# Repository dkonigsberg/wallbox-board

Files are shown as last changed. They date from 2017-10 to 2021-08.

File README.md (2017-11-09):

# Wallbox Interface Board

Seeburg Wall-O-Matic 100

## Introduction
This repository provides the [KiCad](http://kicad-pcb.org/) project
containing the complete circuit schematic, bill-of-materials, and
PCB layout for the Wall-O-Matic Interface Board.

The interface board is a device designed to take a Seeburg Wall-O-Matic
jukebox remote, a common sight on a sterotypical 1950's diner tabletop,
and interface it to a Sonos system via Wi-Fi using an ESP8266 (ESP-12S).

Wall-O-Matic Interface Board

The main repository for the schematics is:
https://github.com/dkonigsberg/wallbox-board

The source code for the firmware that runs on this board is here:
https://github.com/dkonigsberg/wallbox-code

A good overview of the project can be found in these blog posts:
* Part 1 - [Introduction](http://hecgeek.blogspot.com/2017/10/wall-o-matic-interface-1.html)
* Part 2 - [Procuring a Functional Wallbox](http://hecgeek.blogspot.com/2017/10/wall-o-matic-interface-2.html)
* Part 3 - [Decoding the Pulses](http://hecgeek.blogspot.com/2017/10/wall-o-matic-interface-3.html)
* Part 4 - [Inserting Coins](http://hecgeek.blogspot.com/2017/10/wall-o-matic-interface-4.html)
* Part 5 - [Designing the Circuit](http://hecgeek.blogspot.com/2017/10/wall-o-matic-interface-5.html)
* Part 6 - [Developing the Software](http://hecgeek.blogspot.com/2017/10/wall-o-matic-interface-6.html)

You can see a video about the project here:
* [Wallbox Interface Assembly and Testing](https://www.youtube.com/watch?v=2aR7-YdtxFc)

## Notes
The component libraries used in this project are a bit of a hack job, pulling
from many different sources. The KiCad cache file is included so that the
project can actually be opened without having to duplicate this.

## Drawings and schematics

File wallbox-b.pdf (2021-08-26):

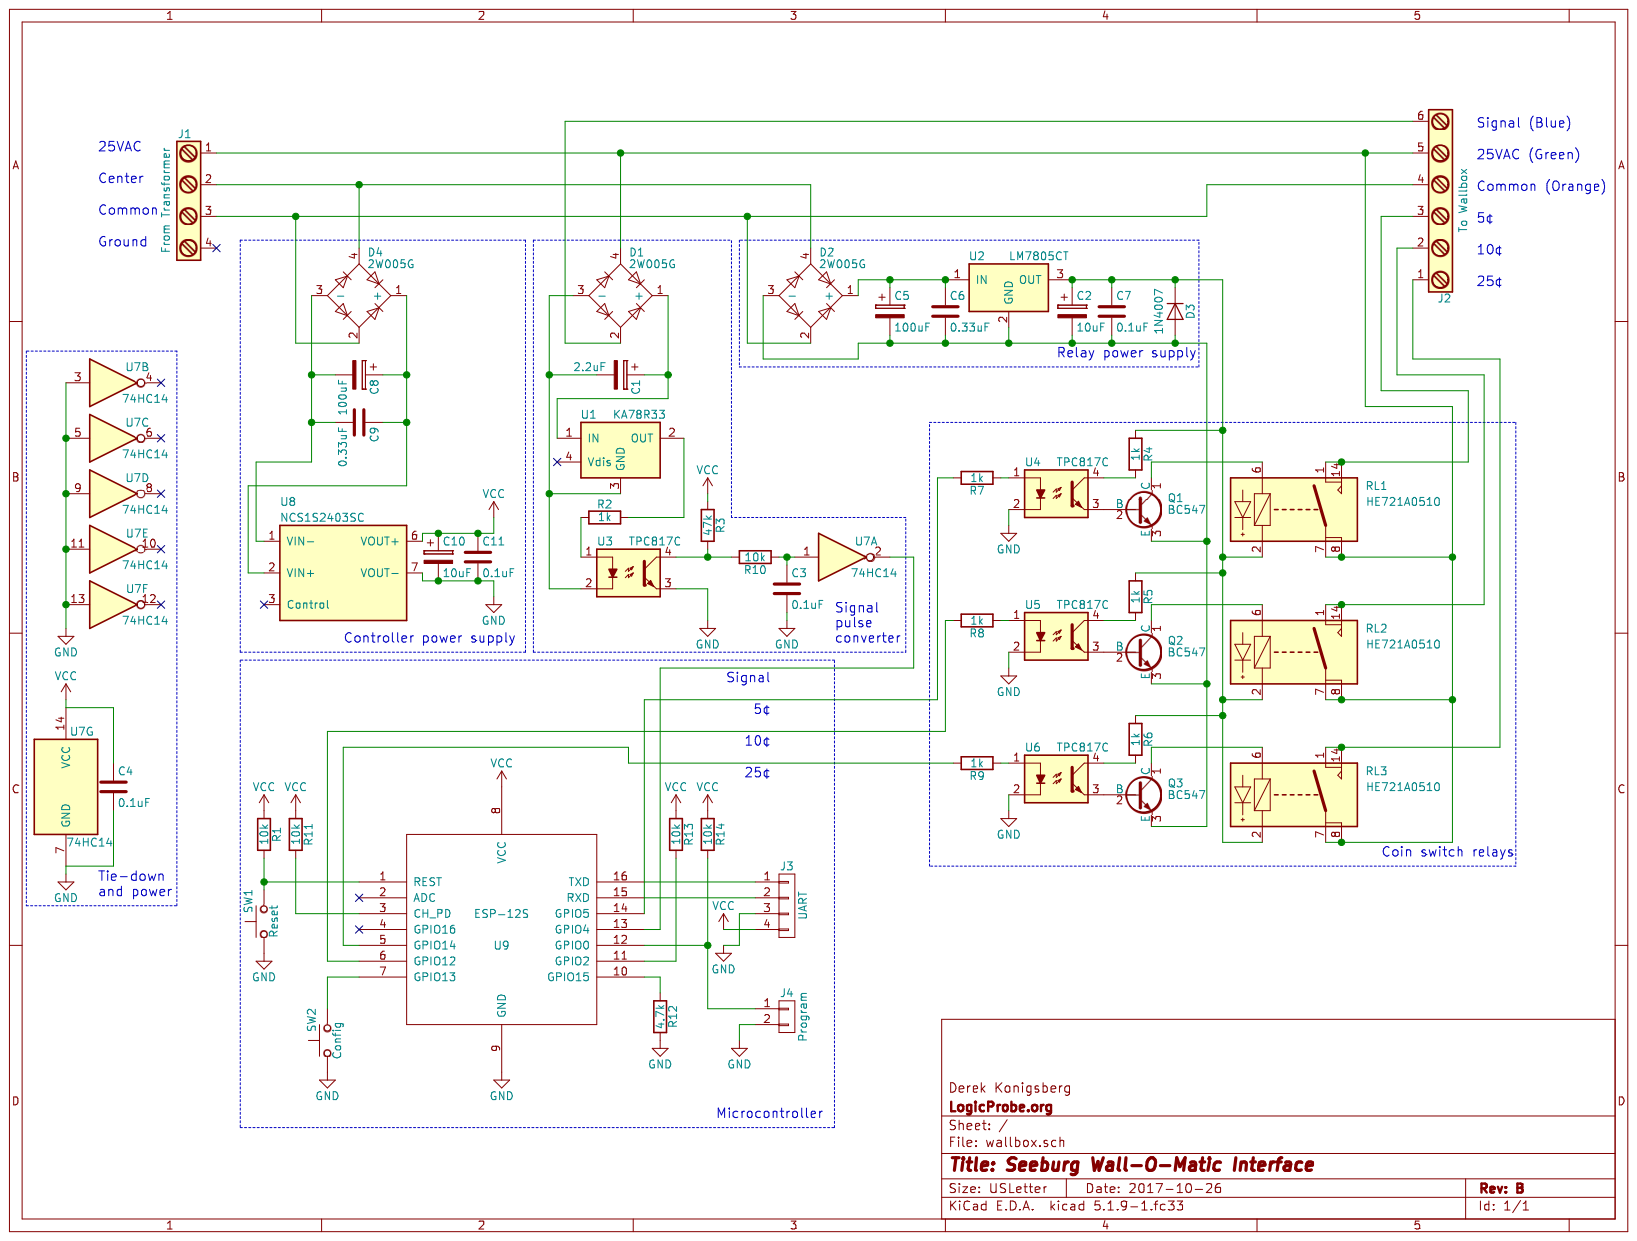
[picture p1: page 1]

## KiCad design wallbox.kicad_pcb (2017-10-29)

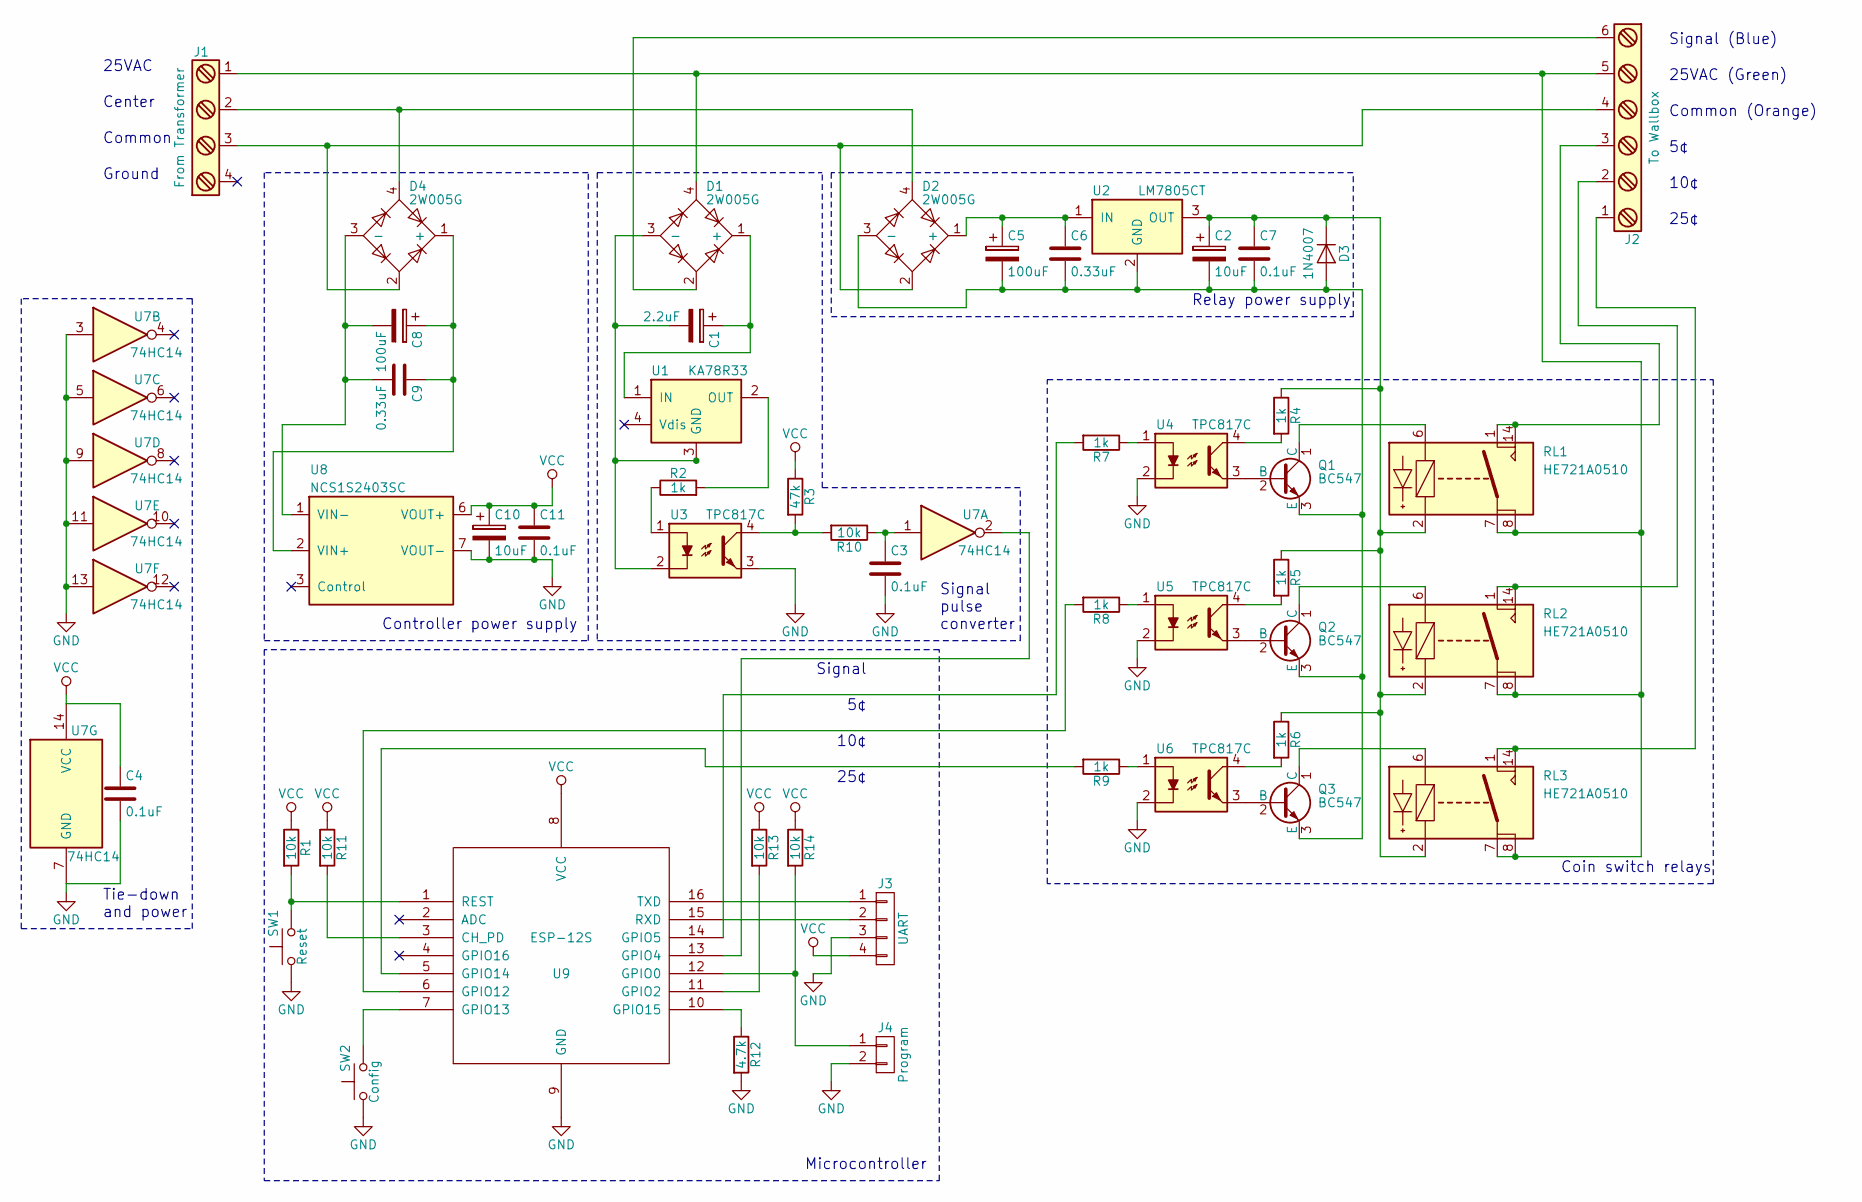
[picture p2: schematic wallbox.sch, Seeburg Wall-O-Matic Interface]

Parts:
C1: 2.2uF; CP_Radial_D5.0mm_P2.00mm; Manufacturer PN UPS1H2R2MDD1TD
C2, C10: 10uF; CP_Radial_D5.0mm_P2.00mm; Manufacturer PN UPW1E100MDD1TD
C3, C4, C7, C11: 0.1uF; C_Disc_D5.0mm_W2.5mm_P5.00mm; Manufacturer PN K104K15X7RF5TH5
C5, C8: 100uF; CP_Radial_D8.0mm_P3.50mm; Manufacturer PN UVZ1H101MPD1TD
C6, C9: 0.33uF; C_Disc_D6.0mm_W2.5mm_P5.00mm; Manufacturer PN KVD500L334M32A0T00
D1, D2, D4: 2W005G; D-BRIDGE-WOG; Manufacturer PN 2W005G-E4/51
D3: 1N4007; D_DO-41_SOD81_P12.70mm_Horizontal; Manufacturer PN 1N4007-TP
J1: From Transformer; TerminalBlock_Pheonix_MKDS1.5-4pol; Manufacturer PN 1729034
J2: To Wallbox; TerminalBlock_Pheonix_MKDS1.5-6pol; Manufacturer PN 1729050
J3: UART; Pin_Header_Straight_1x04_Pitch2.54mm; Manufacturer PN 61300411121
J4: Program; Pin_Header_Straight_1x02_Pitch2.54mm; Manufacturer PN 61300211121
Q1, Q2, Q3: BC547; TO-92_Molded_Narrow; Manufacturer PN BC547BBU
R1, R10, R11, R13, R14: 10k; R_Axial_DIN0207_L6.3mm_D2.5mm_P10.16mm_Horizontal; Manufacturer PN CF14JT10K0
R2, R4, R5, R6, R7, R8, R9: 1k; R_Axial_DIN0207_L6.3mm_D2.5mm_P10.16mm_Horizontal; Manufacturer PN CF14JT1K00
R3: 47k; R_Axial_DIN0207_L6.3mm_D2.5mm_P10.16mm_Horizontal; Manufacturer PN CF14JT47K0
R12: 4.7k; R_Axial_DIN0207_L6.3mm_D2.5mm_P10.16mm_Horizontal; Manufacturer PN CF14JT4K70
RL1, RL2, RL3: HE721A0510; HE700_DIP-14; Manufacturer PN HE721A0510
SW1: Reset; SW_PUSH_6mm_h5mm; Manufacturer PN 1825910-7
SW2: Config; SW_PUSH_6mm_h5mm; Manufacturer PN 1825910-6
U1: KA78R33; TO-220-4_Vertical; Manufacturer PN KA78R33CTU
U2: LM7805CT; TO-220_Vertical; Manufacturer PN LM7805CT
U3, U4, U5, U6: TPC817C; DIP-4_W7.62mm_LongPads; Manufacturer PN TPC817C C9G
U7: 74HC14; DIP-14_W7.62mm_LongPads; Manufacturer PN SN74HC14N
U8: NCS1S2403SC; DCDC-Conv_muRata_NCSxxxxSC; Manufacturer PN NCS1S2403SC
U9: ESP-12S; ESP-12S_SMD; Manufacturer PN ESP-12S

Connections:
GND: C3.2, C4.2, C10.2, C11.2, J3.3, J4.2, R12.2, SW1.1, SW2.1, U3.3, U4.2, U5.2, U6.2, U7.3, U7.5, U7.7 (GND), U7.9, U7.11, U7.13, U8.7 (VOUT-), U9.9 (GND)
unnamed: C1.1, D1.1 (+), U1.1 (IN)
unnamed: C1.2, D1.3 (-), U1.3 (GND), U3.2
unnamed: C2.1, C7.1, D3.1 (K), R4.1, R5.1, R6.1, RL1.2, RL2.2, RL3.2, U2.3 (OUT)
unnamed: C2.2, C5.2, C6.2, C7.2, D2.3 (-), D3.2 (A), Q1.3 (E), Q2.3 (E), Q3.3 (E), U2.2 (GND)
unnamed: C3.1, R10.1, U7.1
unnamed: C5.1, C6.1, D2.1 (+), U2.1 (IN)
unnamed: C8.1, C9.1, D4.1 (+), U8.2 (VIN+)
unnamed: C8.2, C9.2, D4.3 (-), U8.1 (VIN-)
unnamed: D1.2, J2.6
unnamed: D1.4, J1.1 (25VAC), J2.5, RL1.7, RL1.8, RL2.7, RL2.8, RL3.7, RL3.8
unnamed: D2.2, D4.2, J1.3 (Common), J2.4
unnamed: D2.4, D4.4, J1.2 (Center)
unnamed: J2.1, RL3.1, RL3.14
unnamed: J2.2, RL2.1, RL2.14
unnamed: J2.3, RL1.1, RL1.14
unnamed: J3.1, U9.16 (TXD)
unnamed: J3.2, U9.15 (RXD)
unnamed: J4.1, R14.2, U9.12 (GPIO0)
unnamed: Q1.1 (C), RL1.6
unnamed: Q1.2 (B), U4.3
unnamed: Q2.1 (C), RL2.6
unnamed: Q2.2 (B), U5.3
unnamed: Q3.1 (C), RL3.6
unnamed: Q3.2 (B), U6.3
unnamed: R1.2, SW1.2, U9.1 (REST)
unnamed: R2.1, U3.1
unnamed: R2.2, U1.2 (OUT)
unnamed: R4.2, U4.4
unnamed: R5.2, U5.4
unnamed: R6.2, U6.4
unnamed: R7.1, U4.1
unnamed: R7.2, U9.14 (GPIO5)
unnamed: R8.1, U5.1
unnamed: R8.2, U9.6 (GPIO12)
unnamed: R9.1, U6.1
unnamed: R9.2, U9.5 (GPIO14)
unnamed: R3.2, R10.2, U3.4
unnamed: R11.2, U9.3 (CH_PD)
unnamed: R12.1, U9.10 (GPIO15)
unnamed: R13.2, U9.11 (GPIO2)
unnamed: SW2.2, U9.7 (GPIO13)
unnamed: U7.2, U9.13 (GPIO4)
VCC: C4.1, C10.1, C11.1, J3.4, R1.1, R3.1, R11.1, R13.1, R14.1, U7.14 (VCC), U8.6 (VOUT+), U9.8 (VCC)

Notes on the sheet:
25VAC
Common
Ground
Signal (Blue)
25VAC (Green)
Common (Orange)
10¢
25¢
Signal
Center
Signal pulse converter
Relay power supply
Coin switch relays
Tie-down and power
Controller power supply
Microcontroller

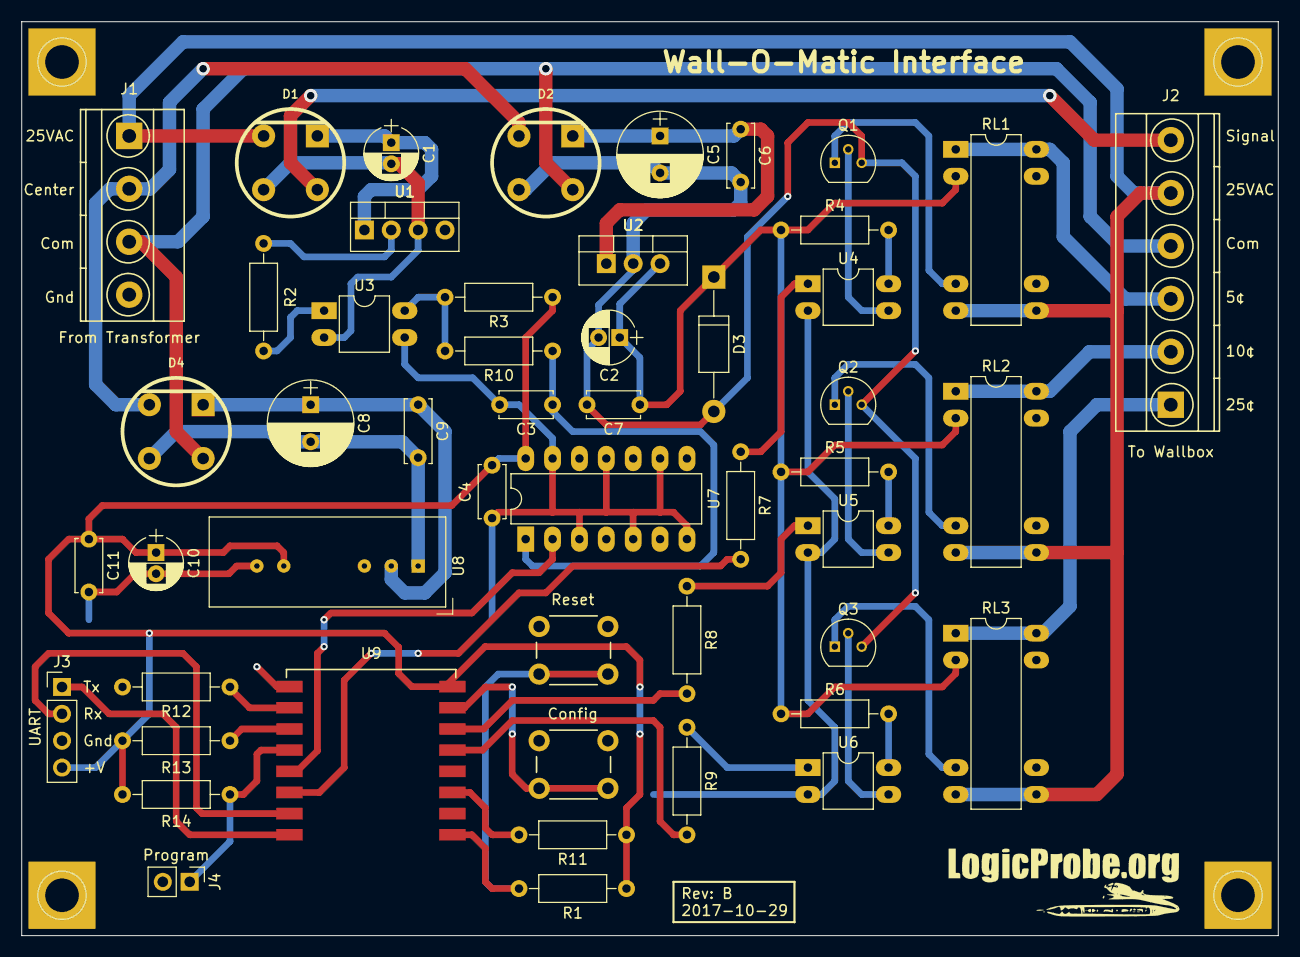
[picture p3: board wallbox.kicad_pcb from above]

Board: 2 copper layers, 118.7 x 86.4 mm, 50 parts (0 on the bottom side), 44 nets.

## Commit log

2017-09-29 Initial empty project
    [wallbox.kicad_pcb, wallbox.sch]
2017-09-30 Initial schematic layout
    [wallbox.sch]
2017-09-30 Footprint associations and imports
    [wallbox.sch]
2017-09-30 Final footprint association fixups
    [wallbox.sch]
2017-10-02 Footprint change
    [wallbox.sch]
2017-10-02 Component fixups and initial PCB layout
    [wallbox.kicad_pcb, wallbox.sch]
2017-10-09 Schematic checkpointing
    [wallbox.kicad_pcb, wallbox.sch]
2017-10-09 Cloned more components into local library
    [wallbox.sch]
2017-10-09 Schematic redraw
    [wallbox.sch]
2017-10-09 Add block descriptions
    [wallbox.sch]
2017-10-09 Misc tweaks
    [wallbox.sch]
2017-10-10 Schematic component details filled in
    [wallbox.sch]
2017-10-10 Updated capacitors, added zener, added DC-DC input components
    [wallbox.sch]
2017-10-10 Filled in screw terminal component details
    [wallbox.sch]
2017-10-12 Added ESP8266 to the schematic
    Hopefully the schematic is actually final now, or close to it.
    [wallbox.sch]
2017-10-12 Respread of updated components on PCB
    Very first step of PCB layout
    [wallbox.kicad_pcb]
2017-10-12 Basic functional grouping of components
    [wallbox.kicad_pcb]
2017-10-12 Updated WOG footprint to separate label
    [wallbox.kicad_pcb]
2017-10-12 Fix WOG footprint pin numbering
    [wallbox.kicad_pcb]
2017-10-12 Routed some elements
    [wallbox.kicad_pcb]
2017-10-12 More submodules routed
    [wallbox.kicad_pcb]
2017-10-12 Getting there, just need to rearrange and route logic power
    [wallbox.kicad_pcb]
2017-10-12 More progress, added board outline
    [wallbox.kicad_pcb, wallbox.sch]
2017-10-12 Include mounting hole footprint
2017-10-12 Updated board labels
    [wallbox.kicad_pcb]
2017-10-12 Initial PCB layout complete
    [wallbox.kicad_pcb]
2017-10-13 Misc fiddling
    [wallbox.kicad_pcb]
2017-10-13 DRC updates
    [wallbox.kicad_pcb]
2017-10-13 Increase via sizes for main power traces
    [wallbox.kicad_pcb]
2017-10-13 Final markings
    [wallbox.kicad_pcb, wallbox.sch]
2017-10-16 First pass of post-rev-A fixes
    Removed Zener diode, that's probably unnecessary and wasn't working as
    intended.
    Fixed coin relay connections (25VAC instead of Common)
    Tweaked some component labels/values
    [wallbox.kicad_pcb, wallbox.sch]
2017-10-22 Fixed silkscreen labels on J3
    [wallbox.kicad_pcb]
2017-10-22 Fixed silkscreen on footprint for U8
    [wallbox.kicad_pcb]
2017-10-22 Tweaked WOG footprint for D1, D2, D4
    Slightly increased drill size to even 0.32, and increased pad size
    accordingly.
    [wallbox.kicad_pcb]
2017-10-22 Change TPC817 parts from DIP-4M version to DIP-4 version
    We could have swapped the footprints, but it makes more sense to just
    order the other size part before making another revision. That way we
    can save the DIP-4M parts for testing, and can keep the smaller
    footprint.
    [wallbox.kicad_pcb, wallbox.sch]
2017-10-26 Added controller reg caps and config button
    [wallbox.sch]
2017-10-26 Manually updated BOM for Rev. A
2017-10-26 Initial BOM changes for Rev. B
2017-10-26 Initial routing for added components
    [wallbox.kicad_pcb]
2017-10-26 Reroute for smaller board (WIP)
    [wallbox.kicad_pcb]
2017-10-26 Opened up a 1.5in gap for condensing the components (WIP)
    [wallbox.kicad_pcb]
2017-10-27 Horizonal shrink
    [wallbox.kicad_pcb]
2017-10-27 Bottom shrink
    [wallbox.kicad_pcb]
2017-10-27 Top shrink
    [wallbox.kicad_pcb]
2017-10-27 Routing cleanup
    [wallbox.kicad_pcb]
2017-10-27 More routing cleanup work
    [wallbox.kicad_pcb]
2017-10-27 Updated WOG footprint for better hole sizes
    [wallbox.kicad_pcb]
2017-10-27 Moved all the relevant BOM data into KiCAD
    [wallbox.sch]
2017-10-27 Refresh netlist based on BOM
2017-10-27 BOM tool config file
2017-10-29 Final markings for Rev B fabrication
    [wallbox.kicad_pcb]
2021-08-26 Add PDF of latest schematic for easy reference
